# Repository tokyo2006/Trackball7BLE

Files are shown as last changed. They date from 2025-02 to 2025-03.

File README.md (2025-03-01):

# ZMK轨迹球接收器

- [中文](README.md)
- [English](README_EN.md)

> 使用睫毛哥的micro52840做的一个接收器,我都是在淘宝买的
> 淘宝链接: [Micro nrf52840](http://e.tb.cn/h.gurVKZZWPhSRJPc?tk=apWz3k02DW5HU7632)

这个接收器需要自行刷bootloader, bootloader文件在bootloader文件夹下面，PCB文件夹中的文件用嘉立创的EDA软件打开。case文件夹里面是壳子，包含了step文件，可以自己打印。

在这个接收器的pcb板上我单独加上了reset的开关，所以你也完全可以把它当做一个单独的轨迹球设备。 轨迹球的模型我是参考的这个项目[Trackball-7](https://www.printables.com/model/83631-trackball-7), PCB也是重新画的，因为原版是rp2040有线的
这是它的原版PCB地址：https://github.com/jfedor2/rp2040-pmw3360

## 固件仓库

固件仓库在[zmk](./zmk/)下面，实际上你也可以直接去我的配置仓库：https://github.com/tokyo2006/zmk-for-cygnus/tree/36_trackball_mouse

## PCB所需元件

| No.  | Quantity | Comment | Value | Manufacturer Part | Manufacturer | Supplier Part | Supplier |
|---:|---|---|---|---|---|---|---|
| 1 | 1 | 1N4148W | | 1N4148W | CJ(江苏长电/长晶)  | C2099 | LCSC |
| 2 | 1 | 1uF | 1uF | CL21B105KBFNNNE | SAMSUNG(三星) | C28323 | LCSC |
| 3 | 1 | 1.5kΩ | 1.5kΩ | 0805W8F1501T5E | UNI-ROYAL(厚声) | C4310 | LCSC |
| 4 | 1 | 1.5kΩ | 1.5kΩ | 0805W8F5101T5E | UNI-ROYAL(厚声) | | LCSC |
| 5 | 1 | 2mΩ | 2mΩ | RLM10FTSMR002 | 大毅科技 | C163090 | LCSC |
| 6 | 1 | 3.3uF | 3.3uF | 0805B335K160NT | FH(风华) | C38332 | LCSC |
| 7 | 1 | 5.1kΩ | 5.1kΩ | 0805W8F5101T5E | UNI-ROYAL(厚声) | C27834 | LCSC |
| 8 | 1 | 10nF | 10nF | CC0805KRX7R9BB103 | YAGEO(国巨) | C83170 | LCSC |
| 9 | 1 | 10uF | 10uF | CL21A106KOQNNNE | SAMSUNG(三星) | C1713 | LCSC |
| 10 | 1 | 100kΩ | 100kΩ | 0805W8F1003T5E | UNI-ROYAL(厚声) | C149504 | LCSC |
| 11 | 1 | 100nF | 100nF | 0805B104K500NT | FH(风华) | C38141 | LCSC |
| 12 | 1 | 100nF | 100nF | CC0603KRX7R9BB104 | YAGEO(国巨) | C14663 | LCSC |
| 13 | 1 | AO3407 | | AO3407 | Hottech(合科泰) | C181093 | LCSC |
| 14 | 1 | B5817WS | B5817WS | 宏迦橙 | C7420329 | LCSC |
| 15 | 1 | BX-TS-26-4417TT | BX-TS-26-4417TT | Bossie(博锡) | C18078110 | LCSC |
| 16 | 1 | CMI126603D09 | | CMI126603D09 | Kailh(凯华) | C400257 | LCSC |
| 17 | 1 | MF200V-11-02P | | MF200V-11-02P | XFCN(兴飞) | C501331 | LCSC |
| 18 | 1 | MF254V-11-04-0743 | | MF254V-11-04-0743 | XFCN(兴飞) | C2889986 | LCSC |
| 19 | 1 | MSS12C02LS-BB2.0 | | MSS12C02LS-BB2.0 | SHOU HAN(首韩) | C3008585 | LCSC |
| 20 | 1 | NCD0805R1 | NCD0805R1 | 国星光电 | C84256 | LCSC |
| 21 | 1 | PH1250-WT-02P | | PH1250-WT-02P | HOOYA(皓宇电子) | C2939411 | LCSC |
| 22 | 1 | PM254-1-03-Z-3.0-C | | PM254-1-03-Z-3.0-C | HCTL(华灿天禄) | C5159935 | LCSC |
| 23 | 1 | N52840 | | | | | |
| 24 | 1 | PMW3610 | | | | | |
| 25 | 1 | TCR2EF19 | TCR2EF19 | | | | |
| 26 | 1 | TP4057 | | TP4057 | UMW(友台半导体) | C725791 | LCSC |
| 27 | 1 | TYPE-C-31-M-13C | | TYPE-C-31-M-13C | 韩国韩荣 | C2848620 | LCSC |

## 装配所需材料

- 一个 57.2mm 轨迹球（我用的是一个斯诺克的台球）
- 三颗2.5mm氮化硅（或氧化锆）轴承球
- 4颗m2x9安装两个按键
- 4颗m2x4安装传感器pcb
- 4颗m2x5安装电源pcb
- 3颗m2x10安装上壳和下壳
- 两个锂电池601245/400mah(我把两个电池并联了，所以一起是800mah了)

## 相关的图片

### pcb

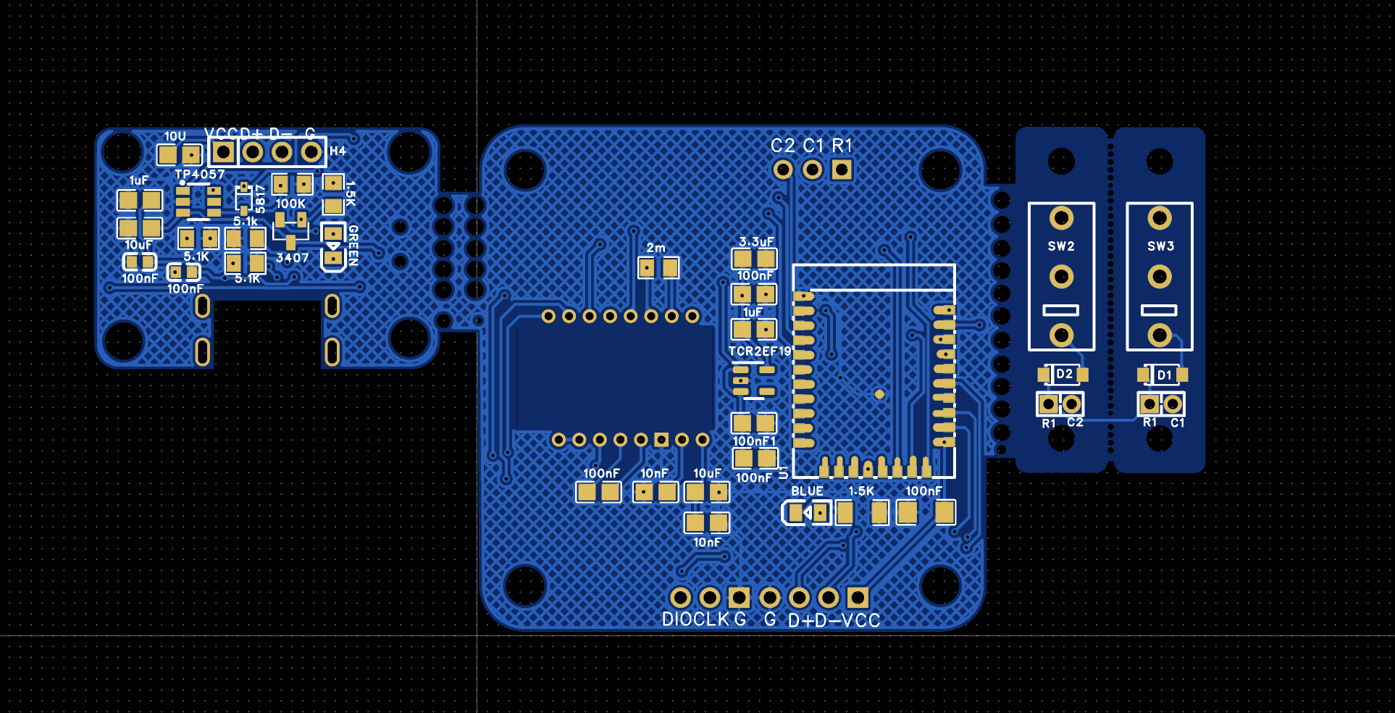
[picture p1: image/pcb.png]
pcb


### model

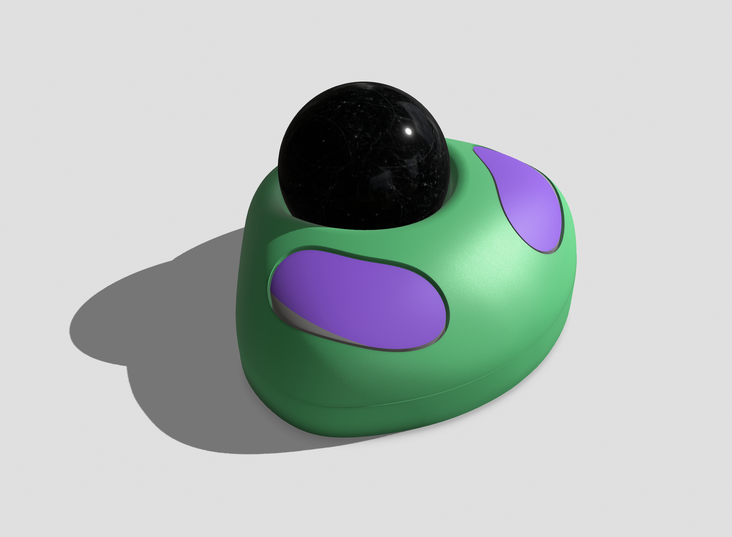
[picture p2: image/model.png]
model


### 我自己的接收器

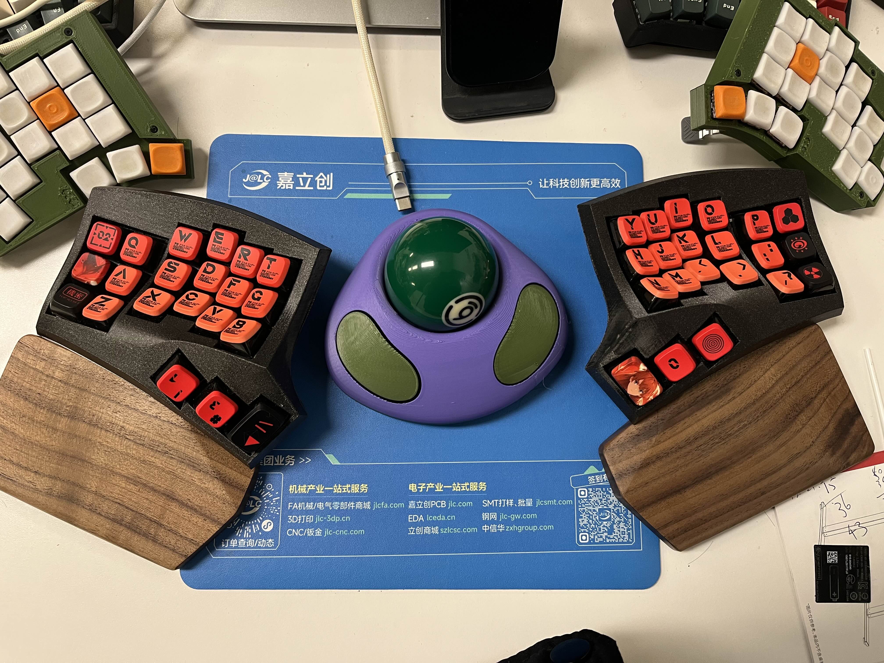
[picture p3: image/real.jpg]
trackball_dongle


## 贡献指南

如果你希望为这个项目贡献代码或文档，请遵循以下步骤：

Fork 本仓库到你的 GitHub 账户。
在你自己的分支中进行修改。
提交你的更改并创建 Pull Request。

## 许可证

本项目在 [CERN Open Hardware Licence Version 2 License](https://opensource.org/license/cern-ohl-p) 下开源，具体许可内容请参见 [LICENSE](./LICENSE) 文件。

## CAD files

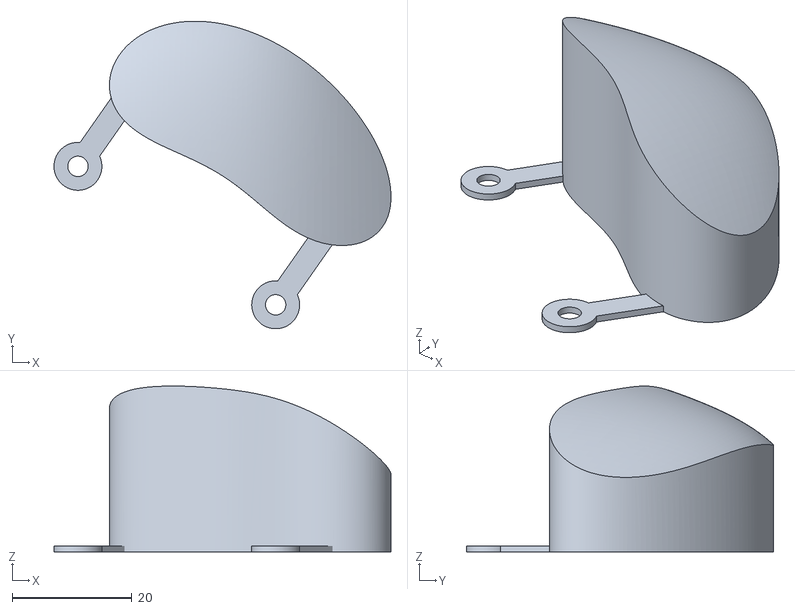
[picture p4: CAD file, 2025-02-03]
case/right_button.stl
56.3 x 51.4 x 27.7

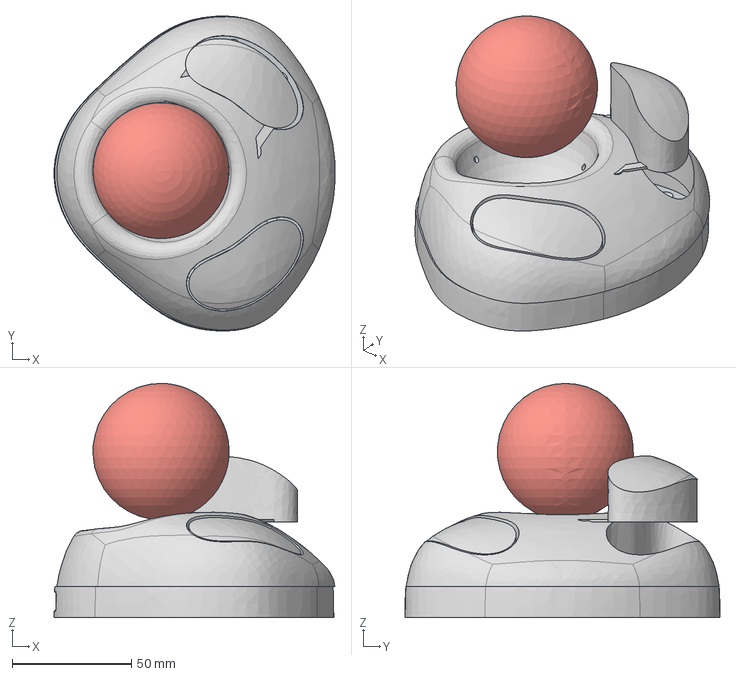
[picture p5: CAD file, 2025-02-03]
case/trackball7.step
117.9 x 132.1 x 98.3 mm
Board
Trackball7.step

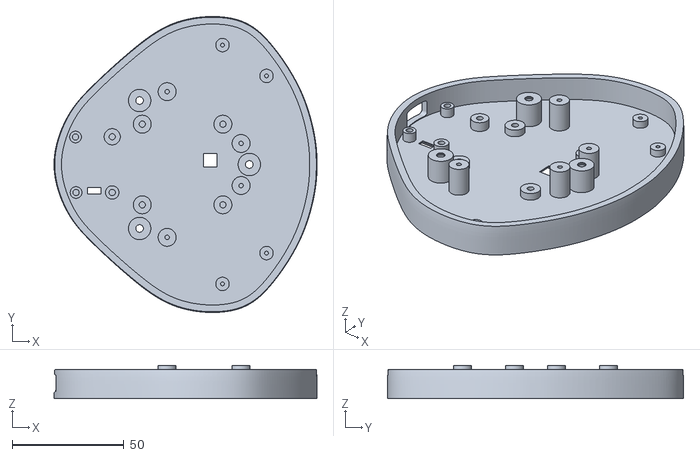
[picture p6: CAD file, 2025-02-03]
case/bottom.stl
117.4 x 132.1 x 14.9

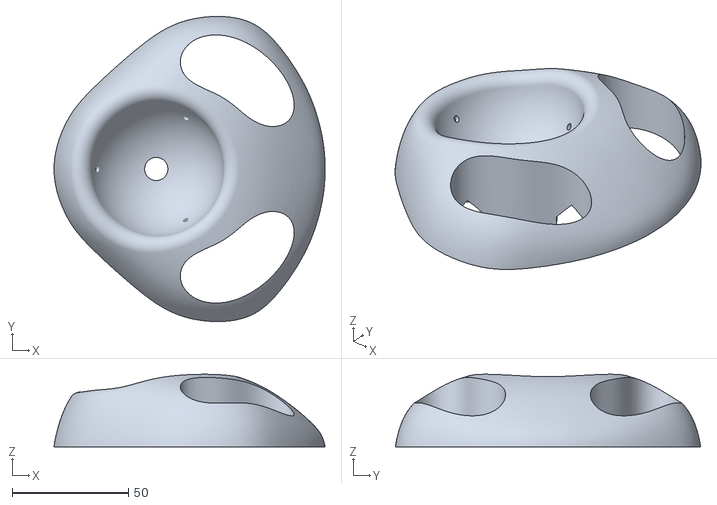
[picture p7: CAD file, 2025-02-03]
case/top.stl
116.8 x 131.5 x 31.2

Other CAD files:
case/left_button.stl
